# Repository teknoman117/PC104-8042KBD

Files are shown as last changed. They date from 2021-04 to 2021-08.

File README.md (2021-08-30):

# PC104-8042KBD

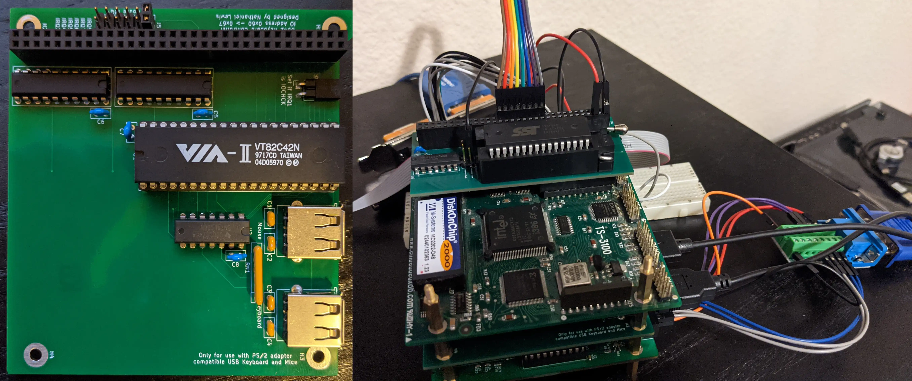
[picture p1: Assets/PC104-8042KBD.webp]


An 8-bit PC/104 keyboard and mouse (PS2) controller for the Technologic Systems TS-3100 (https://www.embeddedarm.com/product-images/TS-3100), which lacks an integrated keyboard controller. Features a VT82C42N controller at the standard IO addresses and is wired to USB connectors. The USB connectors are wired to be equivalent to a passive USB to PS2 adapter, which requires compliant keyboards. Every standalone USB keyboard I've tried to date seemed to be compatible.

The keyboard interrupt is on IRQ 1 for a classic DOS PC, but this interrupt is not available on the PC/104 bus. The TS-3100 has a non-compliant PC/104 bus connector to begin with (most signals are LVCMOS33 due to usage of 74LVC parts and XC9500XL CPLDs, and the DMA pins are replaced with some board specific features like a 386EX chip select unit output and chip select signal overrides for the onboard flash memory), and has IRQ 1 wired in place of IOCHK on later revisions. A jumper is available to connect the keyboard interrupt to IOCHK, or a jumper wire can be used to connect it elsewhere. In the case of my TS-3100s, the IOCHK pin is not electrically connected anywhere, so I have a jumper wire to a GPIO header where IRQ 1 is broken out (DIO1 pin 14). A small BIOS hack is required to enable the IRQ 1 function on this pin at boot.

Licensed under CC-BY-SA 4.0

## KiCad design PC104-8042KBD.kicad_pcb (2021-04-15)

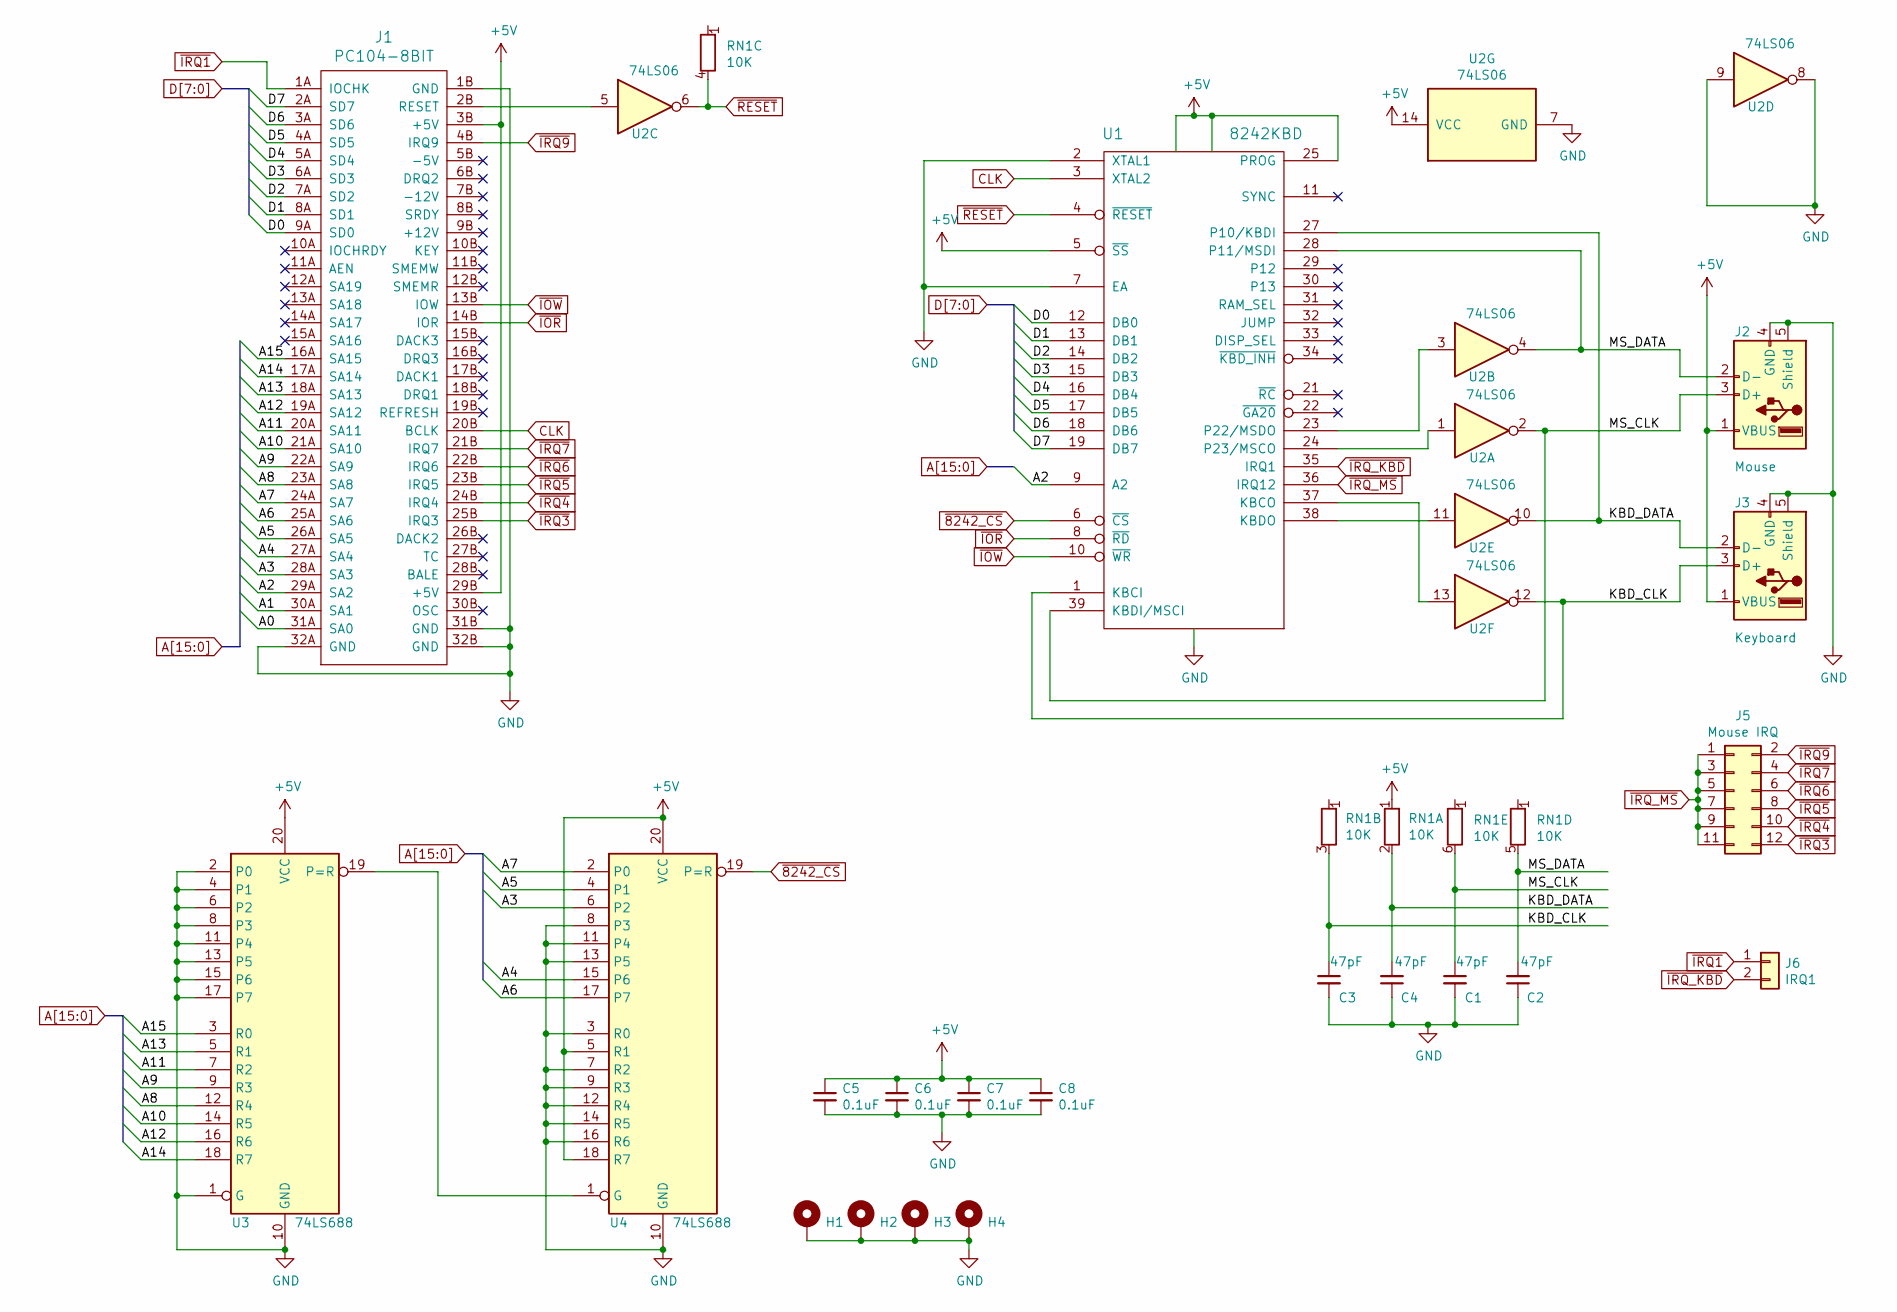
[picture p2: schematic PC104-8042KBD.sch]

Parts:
C1, C2, C3, C4: 47pF; C_Disc_D5.0mm_W2.5mm_P2.50mm
C5, C6, C7, C8: 0.1uF; C_Disc_D5.0mm_W2.5mm_P2.50mm
H1, H2, H3, H4: MountingHole_3.2mm_M3_Pad
J1: PC104-8BIT; PC104-8bit
J2: Mouse; USB_A_Molex_67643_Horizontal
J3: Keyboard; USB_A_Molex_67643_Horizontal
J5: Mouse IRQ; PinHeader_2x06_P2.54mm_Vertical
J6: IRQ1; PinHeader_1x02_P2.54mm_Horizontal
RN1: 10K; R_Array_SIP6
U1: 8242KBD; DIP-40_W15.24mm_Socket
U2: 74LS06; DIP-14_W7.62mm
U3, U4: 74LS688; DIP-20_W7.62mm_Socket

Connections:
+5V: C5.1, C6.1, C7.1, C8.1, J1.3B (+5V), J1.29B (+5V), J2.1 (VBUS), J3.1 (VBUS), RN1.1 (R1.1), U1.5 (~SS), U1.25 (PROG), U1.26 (VCC), U1.40 (VCC), U2.14 (VCC), U3.20 (VCC), U4.5 (R1), U4.18 (R7), U4.20 (VCC)
/A0: J1.31A (SA0)
/A1: J1.30A (SA1)
/A2: J1.29A (SA2), U1.9 (A2)
/A3: J1.28A (SA3), U4.6 (P2)
/A4: J1.27A (SA4), U4.15 (P6)
/A5: J1.26A (SA5), U4.4 (P1)
/A6: J1.25A (SA6), U4.17 (P7)
/A7: J1.24A (SA7), U4.2 (P0)
/A8: J1.23A (SA8), U3.12 (R4)
/A9: J1.22A (SA9), U3.9 (R3)
/A10: J1.21A (SA10), U3.14 (R5)
/A11: J1.20A (SA11), U3.7 (R2)
/A12: J1.19A (SA12), U3.16 (R6)
/A13: J1.18A (SA13), U3.5 (R1)
/A14: J1.17A (SA14), U3.18 (R7)
/A15: J1.16A (SA15), U3.3 (R0)
/D0: J1.9A (SD0), U1.12 (DB0)
/D1: J1.8A (SD1), U1.13 (DB1)
/D2: J1.7A (SD2), U1.14 (DB2)
/D3: J1.6A (SD3), U1.15 (DB3)
/D4: J1.5A (SD4), U1.16 (DB4)
/D5: J1.4A (SD5), U1.17 (DB5)
/D6: J1.3A (SD6), U1.18 (DB6)
/D7: J1.2A (SD7), U1.19 (DB7)
/KBD_CLK: C3.1, J3.3 (D+), RN1.3 (R2.2), U1.1 (KBCI), U2.12
/KBD_DATA: C4.2, J3.2 (D-), RN1.2 (R1.2), U1.27 (P10/KBDI), U2.10
/MS_CLK: C1.1, J2.3 (D+), RN1.6 (R5.2), U1.39 (KBDI/MSCI), U2.2
/MS_DATA: C2.2, J2.2 (D-), RN1.5 (R4.2), U1.28 (P11/MSDI), U2.4
CLK: J1.20B (BCLK), U1.3 (XTAL2)
GND: C1.2, C2.1, C3.2, C4.1, C5.2, C6.2, C7.2, C8.2, H1.1, H2.1, H3.1, H4.1, J1.1B (GND), J1.31B (GND), J1.32A (GND), J1.32B (GND), J2.4 (GND), J2.5 (Shield), J3.4 (GND), J3.5 (Shield), U1.2 (XTAL1), U1.7 (EA), U1.20 (GND), U2.7 (GND), U2.8, U2.9, U3.1 (G), U3.2 (P0), U3.4 (P1), U3.6 (P2), U3.8 (P3), U3.10 (GND), U3.11 (P4), U3.13 (P5), U3.15 (P6), U3.17 (P7), U4.3 (R0), U4.7 (R2), U4.8 (P3), U4.9 (R3), U4.10 (GND), U4.11 (P4), U4.12 (R4), U4.13 (P5), U4.14 (R5), U4.16 (R6)
unnamed: J1.2B (RESET), U2.5
unnamed: U1.23 (P22/MSDO), U2.3
unnamed: U1.24 (P23/MSCO), U2.1
unnamed: U1.37 (KBCO), U2.13
unnamed: U1.38 (KBDO), U2.11
unnamed: U3.19 (P=R), U4.1 (G)
~8242_CS: U1.6 (~CS), U4.19 (P=R)
~IOR: J1.14B (IOR), U1.8 (~RD)
~IOW: J1.13B (IOW), U1.10 (~WR)
~IRQ1: J1.1A (IOCHK), J6.1
~IRQ3: J1.25B (IRQ3), J5.12
~IRQ4: J1.24B (IRQ4), J5.10
~IRQ5: J1.23B (IRQ5), J5.8
~IRQ6: J1.22B (IRQ6), J5.6
~IRQ7: J1.21B (IRQ7), J5.4
~IRQ9: J1.4B (IRQ9), J5.2
~IRQ_KBD: J6.2, U1.35 (IRQ1)
~IRQ_MS: J5.1, J5.3, J5.5, J5.7, J5.9, J5.11, U1.36 (IRQ12)
~RESET: RN1.4 (R3.2), U1.4 (~RESET), U2.6

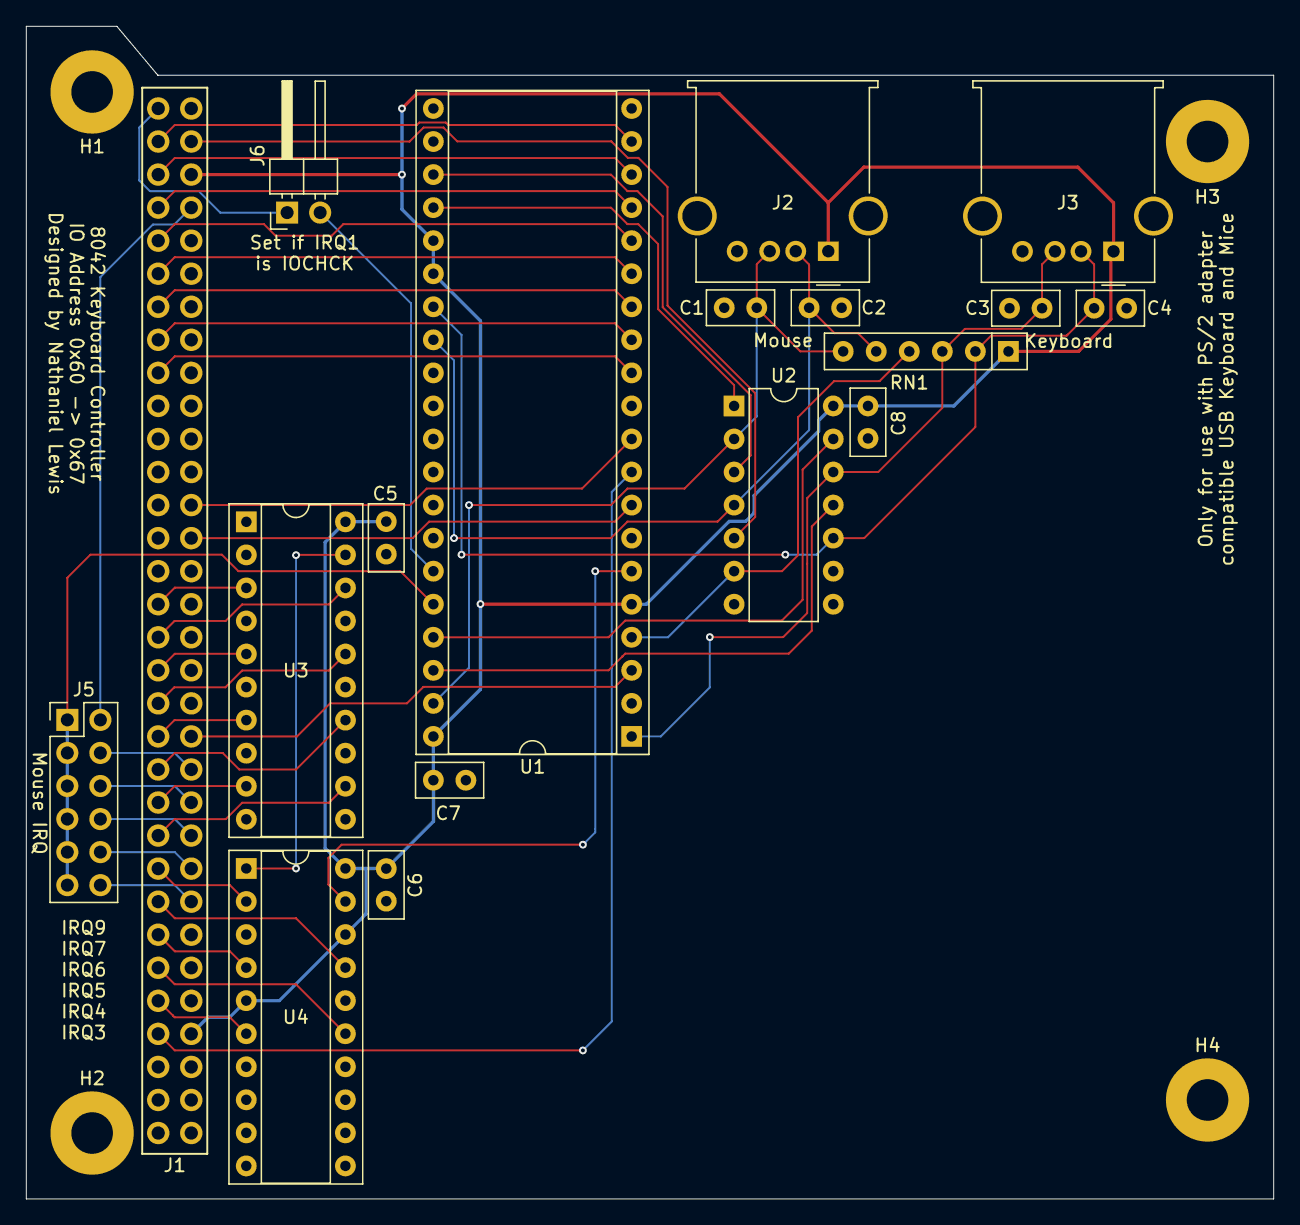
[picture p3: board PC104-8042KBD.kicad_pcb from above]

Board: 2 copper layers, 95.9 x 90.1 mm, 22 parts (0 on the bottom side), 48 nets.

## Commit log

2021-04-15 state at manufacturing
    [PC104-8042KBD.kicad_pcb, PC104-8042KBD.sch]
2021-08-30 add photo of assembled board
2021-08-30 add gerbers for revision 1.0
    [PC104-8042KBD-B_Cu.gbl, PC104-8042KBD-B_Mask.gbs, PC104-8042KBD-B_SilkS.gbo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]
